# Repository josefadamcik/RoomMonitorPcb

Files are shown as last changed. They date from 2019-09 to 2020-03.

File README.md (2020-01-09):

# RoomMonitorPcb

PCB design files (KiCad) for DYI room conditions monitor. 

- ESP8266 wifi connection & brain
- SHT21 - temperature and humidity sensor
- BH1750 - light intensity sensor.

All sesnors communicate via I2C bus. Data are sent to a MQTT broker.
¯
2 prototypes and the actual PCB version

[A repository with firmware is also available on github.](https://github.com/josefadamcik/RoomMonitor)

More information can be found in this series of blog posts:

- [ESP8266 based room-conditions monitor, Part 1](https://josef-adamcik.cz/electronics/esp8266-based-room-conditions-monitor-part-1.html)
- [ESP8266 based room-conditions monitor, part 2: PCB](https://josef-adamcik.cz/electronics/esp8266-based-room-conditions-monitor-part-2.html)

There is also another project for a remote MQTT display for measured data:

- [Github project RoomMonitorClient](https://github.com/josefadamcik/RoomMonitorClient)
- blog post [Freeform ESP8266 OLED MQTT client](https://josef-adamcik.cz/electronics/freeform-esp8266-based-mqtt-oled-client.html)

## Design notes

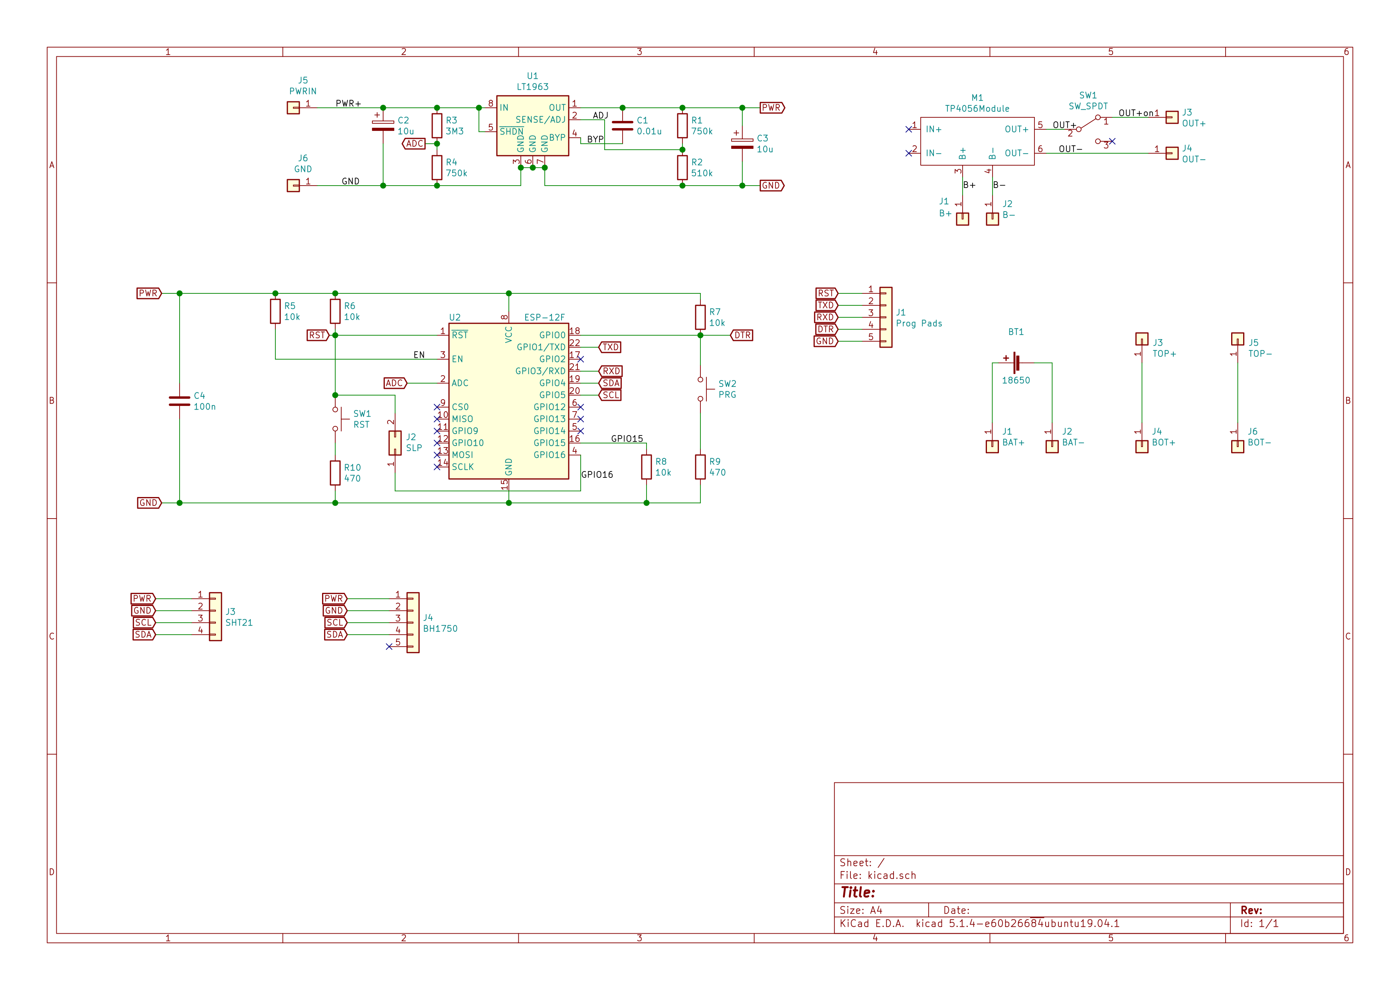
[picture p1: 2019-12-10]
images/full_schematic.png

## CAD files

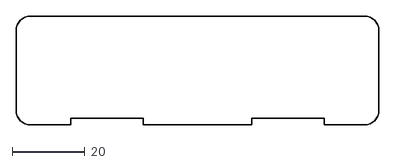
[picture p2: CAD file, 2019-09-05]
design/top_edge.dxf
100.0 x 30.0

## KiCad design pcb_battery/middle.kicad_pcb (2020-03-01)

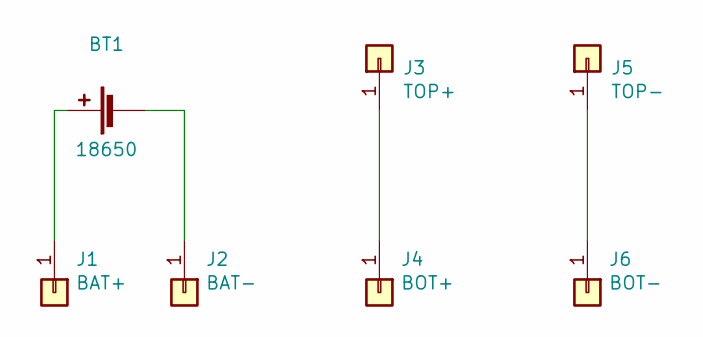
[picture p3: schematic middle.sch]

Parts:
BT1: 18650; BatteryHolder_MPD_BH-18650-PC2
J1: BAT+; SolderWirePad_1x01_Drill0.8mm
J2: BAT-; SolderWirePad_1x01_Drill0.8mm
J3: TOP+; SolderWirePad_1x01_Drill0.8mm
J4: BOT+; SolderWirePad_1x01_Drill0.8mm
J5: TOP-; SolderWirePad_1x01_Drill0.8mm
J6: BOT-; SolderWirePad_1x01_Drill0.8mm

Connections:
unnamed: BT1.1 (+), J1.1
unnamed: BT1.2 (-), J2.1
unnamed: J3.1, J4.1
unnamed: J5.1, J6.1

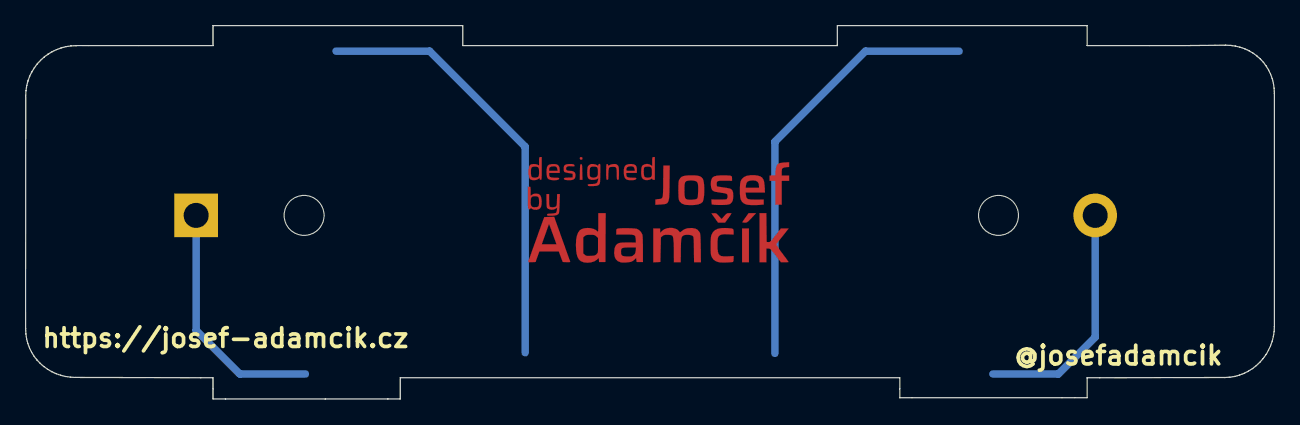
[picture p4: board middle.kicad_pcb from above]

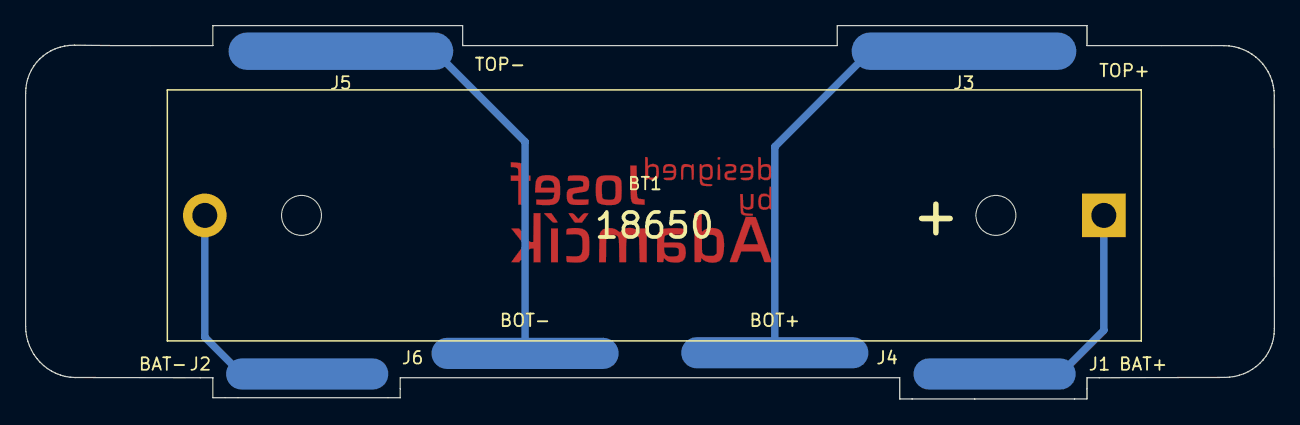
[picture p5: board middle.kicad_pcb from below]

Board: 2 copper layers, 100.0 x 29.9 mm, 8 parts (7 on the bottom side), 4 nets.

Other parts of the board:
Ref**: Val**; josef_adamcik_20mm_cu_mask

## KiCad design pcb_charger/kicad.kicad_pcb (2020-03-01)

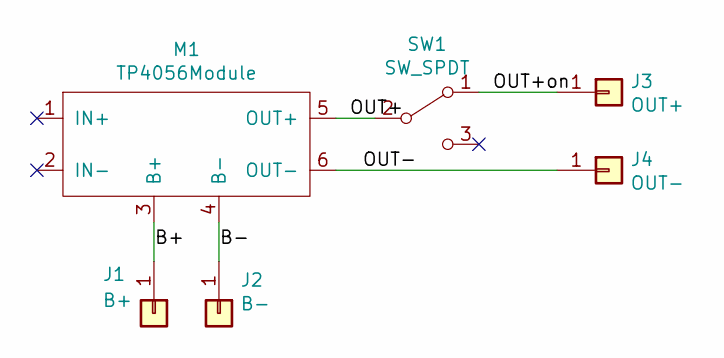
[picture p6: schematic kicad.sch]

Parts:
J1: B+; SolderWirePad_1x01_Drill0.8mm
J2: B-; SolderWirePad_1x01_Drill0.8mm
J3: OUT+; SolderWirePad_1x01_Drill0.8mm
J4: OUT-; SolderWirePad_1x01_Drill0.8mm
M1: TP4056Module; TP4056_Module
SW1: SW_SPDT; SW_SPDT_PCM12

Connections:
/B+: J1.1, M1.3 (B+)
/B-: J2.1, M1.4 (B-)
/OUT+: M1.5 (OUT+), SW1.2 (B)
/OUT+on: J3.1, SW1.1 (A)
/OUT-: J4.1, M1.6 (OUT-)

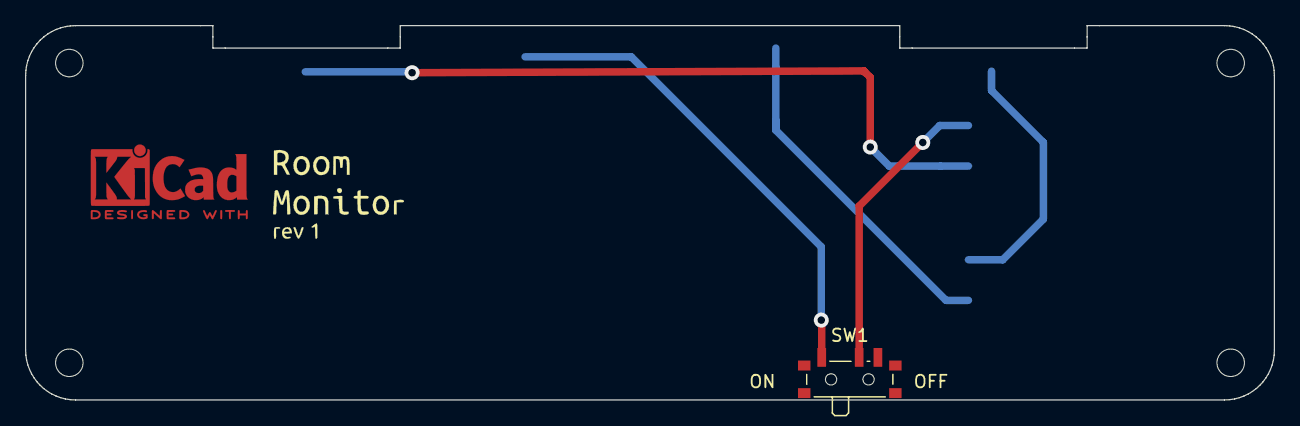
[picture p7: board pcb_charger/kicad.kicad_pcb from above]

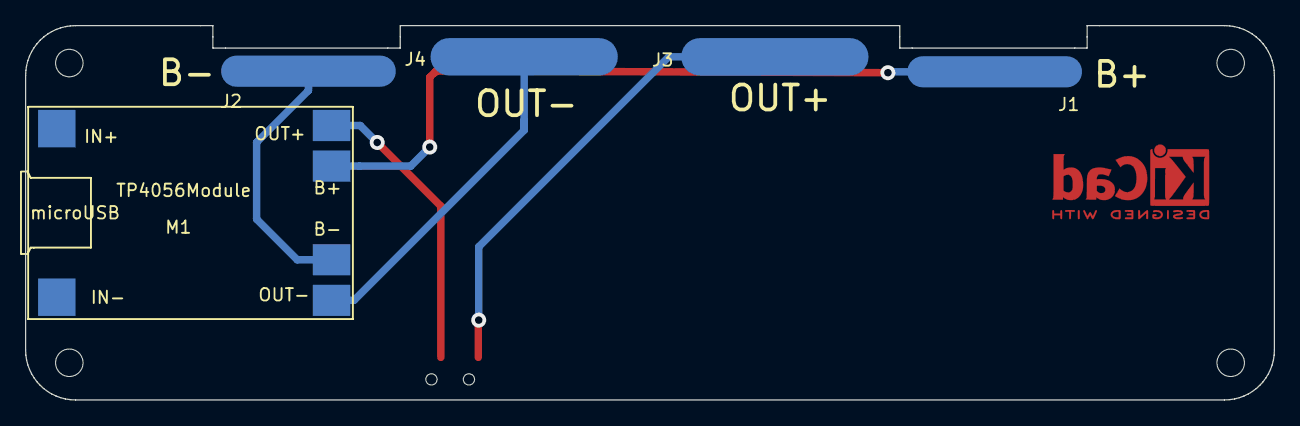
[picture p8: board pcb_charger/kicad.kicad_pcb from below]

Board: 2 copper layers, 100.0 x 30.0 mm, 7 parts (5 on the bottom side), 5 nets.

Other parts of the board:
Ref**: Val**; roommonitor-rev

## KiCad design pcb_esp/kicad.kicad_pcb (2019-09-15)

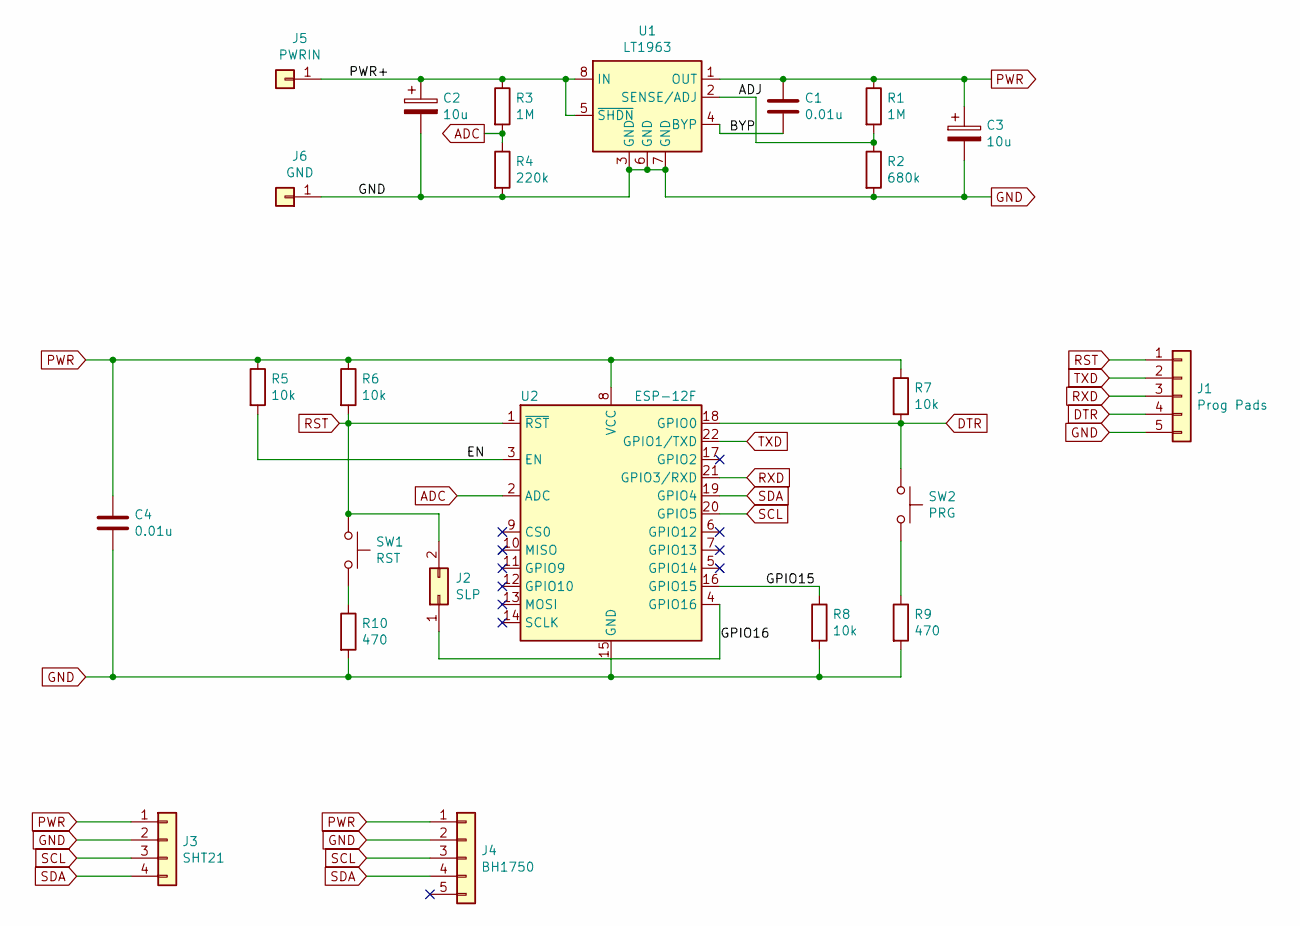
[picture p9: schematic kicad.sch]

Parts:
C1, C4: 0.01u; C_1206_3216Metric_Pad1.42x1.75mm_HandSolder
C2, C3: 10u; CP_Radial_D5.0mm_P2.50mm
J1: Prog Pads; PinHeader_1x05_P2.54mm_Vertical
J2: SLP; PinHeader_1x02_P2.54mm_Vertical
J3: SHT21; PinSocket_1x04_P2.54mm_Vertical
J4: BH1750; PinSocket_1x05_P2.54mm_Vertical
J5: PWRIN; SolderWirePad_1x01_Drill1mm
J6: GND; SolderWirePad_1x01_Drill1mm
R1, R3: 1M; R_1206_3216Metric
R2: 680k; R_1206_3216Metric
R4: 220k; R_1206_3216Metric
R5, R6, R7, R8: 10k; R_1206_3216Metric
R9, R10: 470; R_1206_3216Metric
SW1: RST; SW_SPST_SKQG_WithStem
SW2: PRG; SW_SPST_SKQG_WithStem
U1: LT1963; SOIC-8_3.9x4.9mm_P1.27mm
U2: ESP-12F; ESP-12E

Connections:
/ADJ: R1.2, R2.1, U1.2 (SENSE/ADJ)
/BYP: C1.2, U1.4 (BYP)
/EN: R5.2, U2.3 (EN)
/GPIO15: R8.1, U2.16 (GPIO15)
/GPIO16: J2.1, U2.4 (GPIO16)
/PWR+: C2.1, J5.1, R3.1, U1.5 (~SHDN), U1.8 (IN)
ADC: R3.2, R4.1, U2.2 (ADC)
DTR: J1.4, R7.2, SW2.1, U2.18 (GPIO0)
GND: C2.2, C3.2, C4.2, J1.5, J3.2, J4.2, J6.1, R2.2, R4.2, R8.2, R9.2, R10.2, U1.3 (GND), U1.6 (GND), U1.7 (GND), U2.15 (GND)
unnamed: R9.1, SW2.2
unnamed: R10.1, SW1.2
PWR: C1.1, C3.1, C4.1, J3.1, J4.1, R1.1, R5.1, R6.1, R7.1, U1.1 (OUT), U2.8 (VCC)
RST: J1.1, J2.2, R6.2, SW1.1, U2.1 (~RST)
RXD: J1.3, U2.21 (GPIO3/RXD)
SCL: J3.3, J4.3, U2.20 (GPIO5)
SDA: J3.4, J4.4, U2.19 (GPIO4)
TXD: J1.2, U2.22 (GPIO1/TXD)

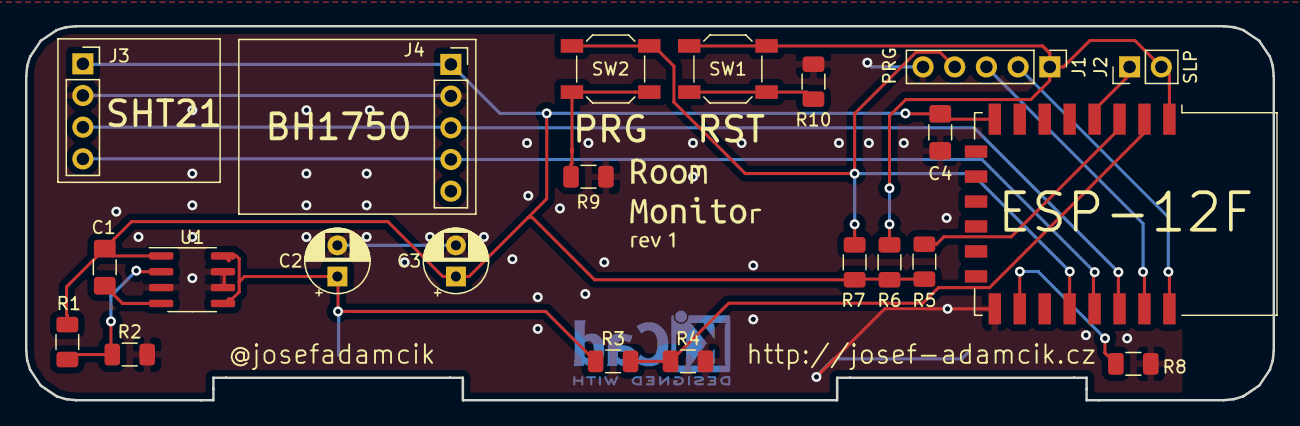
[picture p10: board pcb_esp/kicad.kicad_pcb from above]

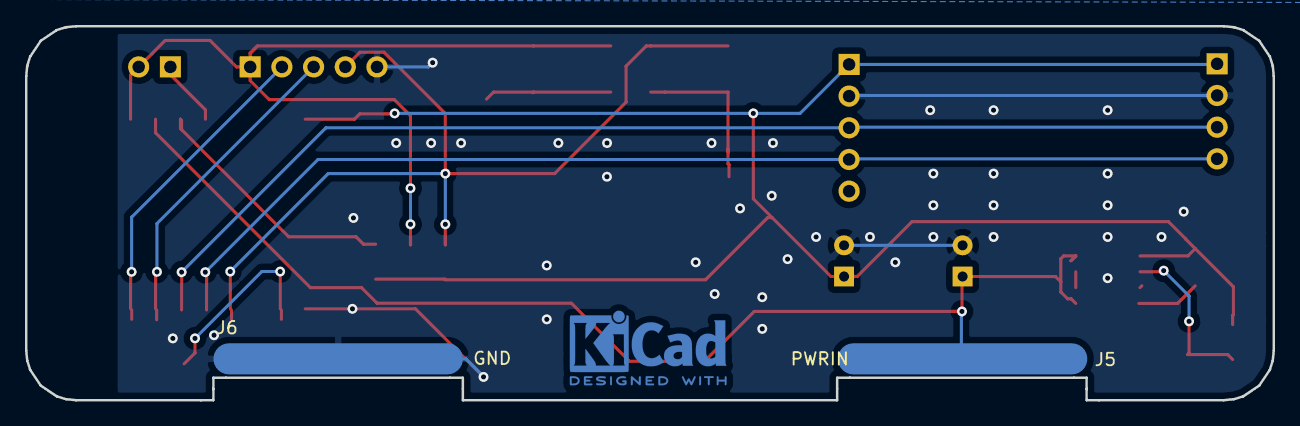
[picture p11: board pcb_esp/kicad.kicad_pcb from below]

Board: 2 copper layers, 100.0 x 30.0 mm, 25 parts (2 on the bottom side), 17 nets.

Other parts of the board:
Ref**: Val**; roommonitor-rev

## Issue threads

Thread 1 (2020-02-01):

List a detailed bill of materials

nunoronconcouto, 2020-02-01:
Hi!!
Can you put the list of material needed to set up your project.
I already have the PCBs from https://jlcpcb.com/
Please..

Thanks

josefadamcik, 2020-02-03:
Hi,
there is a rough list of parts in the article on my website: https://josef-adamcik.cz/electronics/esp8266-based-room-conditions-monitor-part-2.html

It looks like this:

-  SHT21 breakout and BH1750 breakout
-  ESP-12F module
-  TP4056 charging and protection module for 18650 Make sure you buy the one with the protection chip, some models have only the charging part and not the protection. You should never connect a Li-On cell without protection a circuit.
-  bunch of 1206 resistors (see the schematic for values)
-  a few 1206 capacitors (see the schematic for values)
-  2 THT electrolytic capacitors (10uF)
-  few pin headers (female) or you could solder the sensor boards directly to the board
-  a switch and 2 buttons
-  cell holder for 18650
-  a Li-On cell (18650)

A few items have a links to aliexpress in the [blogpost]( https://josef-adamcik.cz/electronics/esp8266-based-room-conditions-monitor-part-2.html
). I don't think including links to aliexpress is a good idea for a good BOM on github (they will stop working sooner or later).

**I don't have any more detailed BOM**. Keep in mind most of the parts were parts I already had in stock and I just measured them and picked a footprint from KiCad libraries for them. I have no part numbers or anything for most of them since they are sourced from aliexpress or salvaged from other projects.

I believe with some work it should be possible to put the BOM together based on the list above, links in the article and information from KiCad project (schematic, mapping, footprints). **Feel free to do that and create a pull-request with BOM to help others.**

Closed 2020-02-03.

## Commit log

2019-08-28 Add epmty kicad project
    [kicad.kicad_pcb, kicad.sch]
2019-08-28 Symbol for LT1763, power schematic
    [kicad.sch]
2019-08-28 Footprints and symbols for charger, updated schematic.
    [kicad.kicad_pcb, kicad.sch]
2019-09-04 Rename project
    [kicad.kicad_pcb, kicad.sch]
2019-09-04 Copy to second project
    [kicad.kicad_pcb, kicad.sch]
2019-09-04 WIP first board for ESP and regulator
    [kicad.kicad_pcb, kicad.sch]
2019-09-05 Edge layer for to pcb, making it smaller (30 wide)
    [kicad.kicad_pcb, kicad.sch, top_edge.dxf]
2019-09-05 Add pads for power contacts and main mechanical connection
    [kicad.kicad_pcb]
2019-09-07 ESP module - placed and connected
    [kicad.kicad_pcb, kicad.sch]
2019-09-07 Change button footprint, ad kicad logo.
    [kicad.kicad_pcb, kicad.sch]
2019-09-07 Small, mostly visual, improvements
    [kicad.kicad_pcb]
2019-09-08 Add firs draft of the middle (battery) pcb
    [kicad.kicad_pcb, middle.kicad_pcb, middle.sch]
2019-09-08 Add the bottom pcb.
    [kicad.kicad_pcb, kicad.sch, middle.kicad_pcb]
2019-09-08 All 3 parts done
    [kicad.kicad_pcb, middle.kicad_pcb]
2019-09-08 Add GND connecting vias to the main PCB
    [kicad.kicad_pcb]
2019-09-08 Few more small improvements.
    [kicad.kicad_pcb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]
2019-09-15 Fix lt1763 symbol (swapped gnd and byp pins) and fix pcb
    [kicad-B_Cu.gbr, kicad-B_Mask.gbr, kicad-B_Paste.gbr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]
2019-09-15 Gerber zip update
2019-09-15 Last changes to the charger board and gerbers
    [kicad-B_Cu.gbr, kicad-B_Mask.gbr, kicad-B_SilkS.gbr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]
2019-12-10 Organise files a bit
    [kicad.sch, top_edge.dxf]
2020-03-01 Update trace and via sizes for battery and charger
    [kicad.kicad_pcb, middle.kicad_pcb]
